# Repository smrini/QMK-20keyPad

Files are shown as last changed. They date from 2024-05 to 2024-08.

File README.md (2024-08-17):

# Custom QMk 20KeyPad 
Unleash enhanced productivity and personalize your workflow with this customizable 20-key macro keypad. This project empowers you to craft intricate macros, shortcuts, and key combinations that seamlessly integrate with your existing setup.

# Key Advantages:

* QMK Compatibility: QMK unlocks a universe of possibilities – program sophisticated macros, intricate key combinations, and layer functionalities to tailor the keypad precisely to your needs.
* 20-Key Matrix Design: Space-saving matrix layout that allows you to create a compact yet efficient keypad that perfectly complements your workspace. Whether you favour dedicated media controls, application launchers, or complex macros...
* RP2040 Microcontroller: The RP2040zero ensures smooth performance for a cheap price. 
* Multi-layer design: A functionality that gives the ability to do more than one thing to the same switch. or maybe a different layout for different uses.
* Embrace Customization: This project serves as a foundation for your creativity! Feel free to adapt the design to your preferred layout to create functionalities that perfectly align with your workflow.

# Building Your Macro Keypad:

Hardware Procurement:

* RP2040 microcontroller board (e.g., Raspberry Pi Pico)
* 20 Mechanical keyboard switches (select the switch type that best suits your typing preference – tactile, clicky, or linear)
* Keycaps (ensure compatibility with your chosen switches)
* Diodes (optional, for improved matrix scanning)
* copper wires
* 3D-printer (Or Order it online)

Required Skills:

* The knowledge of what is command line.
* An idea about QMK MSYS Commands.
* Previous use of Visual Studio (If you are planning to modify the code).
* Soldering skills

Advanced skills:
* C programming.
* .json files.
* qmk firmware.

Software Arsenal:

* [QMK Firmware](https://docs.qmk.fm/)
  
* [QMK MSYS](https://msys.qmk.fm/)

* Text editor or IDE of your choice (e.g., Visual Studio Code)

# Documentation:

Detailed instructions for hardware assembly, firmware flashing, and keymap configuration will be readily available within the project repository. Additionally, the repository may include resources or links to helpful guides that provide further assistance with the build and programming process.

You can find further information about the 3D model on my [Printables](https://www.printables.com/@GreenBit_1562343) Profile. Also [Here](https://www.printables.com/model/841830-qmk-20keymacropad), or directly [Here](https://github.com/smrini/QMK-20keyPad/tree/main/Assets/Building%20Guide).

# Contributions:

This is a collaborative effort! We welcome contributions from the keyboard enthusiast community. Submit pull requests with enhancements, bug fixes, or innovative features to help us build a robust and feature-rich macro keypad solution.

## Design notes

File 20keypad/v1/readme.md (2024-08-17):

# Handwired 20keyPad v1

20KeyPad

A 20 Key (4x5) Macropad that could be reprogrammed to suit your need, it has got 3 layers, and all the needed files are included (QMK files, 3D printables files, Buttons labels...). [More info on my github](https://github.com/smrini/QMK-20keyPad)

-   Keyboard Maintainer: [Said Mrini](https://github.com/smrini).
-   Personal Website: www.saidmrini.com

## Hardware Supported:

You can use the RP2040zero or any other microcontroller from the same series (RP2040).
You can't use a PCB, because the space is a bit tight, So you will have to hand-wire everything.

## Hardware Availability:

-   MicroController: [rp2040zero](https://es.aliexpress.com/item/1005006051130777.html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)
-   Diodes:[1N4148](https://es.aliexpress.com/item/1005006127068810.html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)
-   Keycaps: [Black and white keycaps](https://es.aliexpress.com/item/1005006213262185.html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) 
- Switches: [Red Switches](https://es.aliexpress.com/item/1005005908829758.html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)
-   3D files: [Printables](https://www.printables.com/model/841830-qmk-20keymacropad)

### Compiling example for this keyboard:

    qmk compile -kb 20keypad/v1 -km default

### Flashing example for this keyboard:

    qmk flash -kb 20keypad/v1 -km default

### Attention:

    You can compile and use the code as it is as long as you are using the same microcontroller and the same pins used in the schematic.

    just download the files, open QMK MSYS and use this command: qmk flash -kb 20keypad/v1 -km default
    You can modify the code and layers to whatever it suits you.

    if you decide to use different pins, you must change the Pinout in the keyboard.json file.
    if you decide to use a different MicroController, you must change some related information in the keyboard.json file.

See the [build environment setup](https://docs.qmk.fm/#/getting_started_build_tools) and the [make instructions](https://docs.qmk.fm/#/getting_started_make_guide) for more information. Brand new to QMK? Start with our [Complete Newbs Guide](https://docs.qmk.fm/#/newbs).

## Bootloader

Getting into bootloader:

-   **Physical reset button**: there are 2 buttons on the back of the PCB - press and hold the Boot button, don't leave it yet, press the reset button one time, after you leave it, remove your hand from the boot button.
-   **Keycode in layout**: Press and hold the 3rd key from left on the top row then press the last key on the same row. The LED will blink 3 times, then hold in red, till the flash is complete

## Useful Resources:

-   [keykodes list](https://docs.qmk.fm/#/keycodes)
-   [Matrix and hand wiring](https://docs.qmk.fm/#/hand_wire)
-   [more about info.json file](https://github.com/qmk/qmk_firmware/blob/master/docs/reference_info_json.md)
-   [More about the Keymap.c file](https://github.com/qmk/qmk_firmware/blob/master/docs/keymap.md)
-   [RGB Light](https://docs.qmk.fm/#/feature_rgblight)
-   [Command Line](https://github.com/qmk/qmk_firmware/blob/master/docs/cli_commands.md)

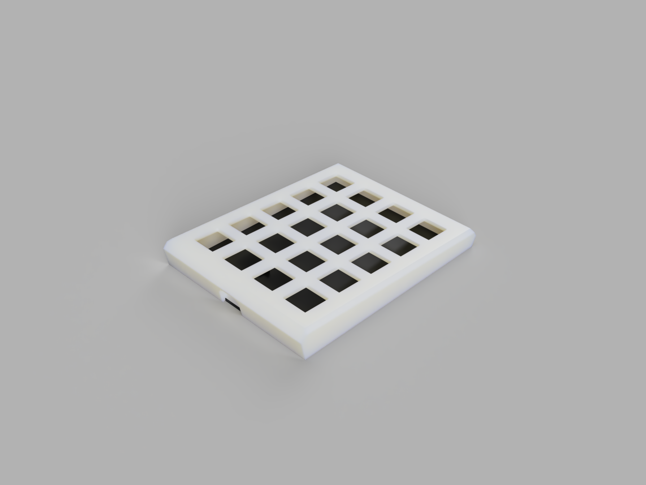
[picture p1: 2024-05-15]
Assets/20KeyPad-V1/Pictures/frame.3.png

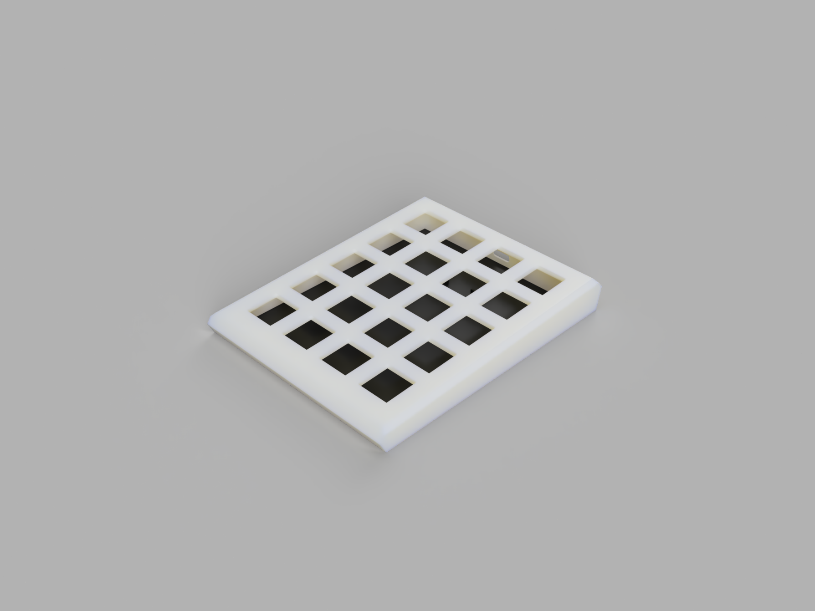
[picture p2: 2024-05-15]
Assets/20KeyPad-V1/Pictures/frame.0.png

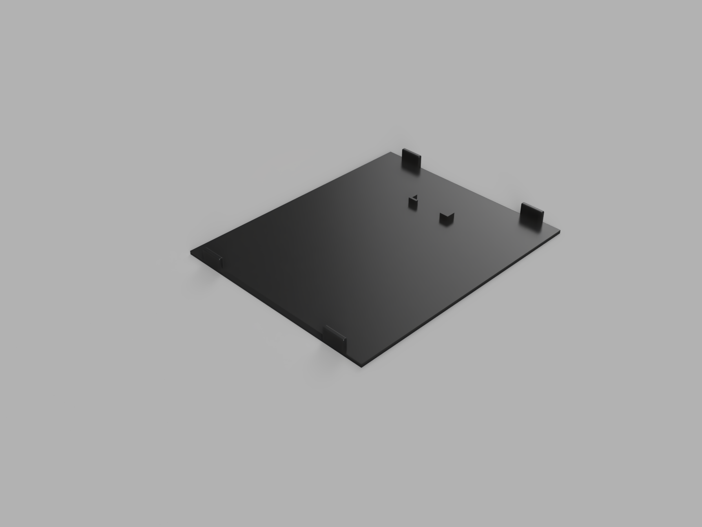
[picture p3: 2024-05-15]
Assets/20KeyPad-V1/Pictures/NumPad_2024-May-01_11-30-11PM-000_CustomizedView23081530173_png.png

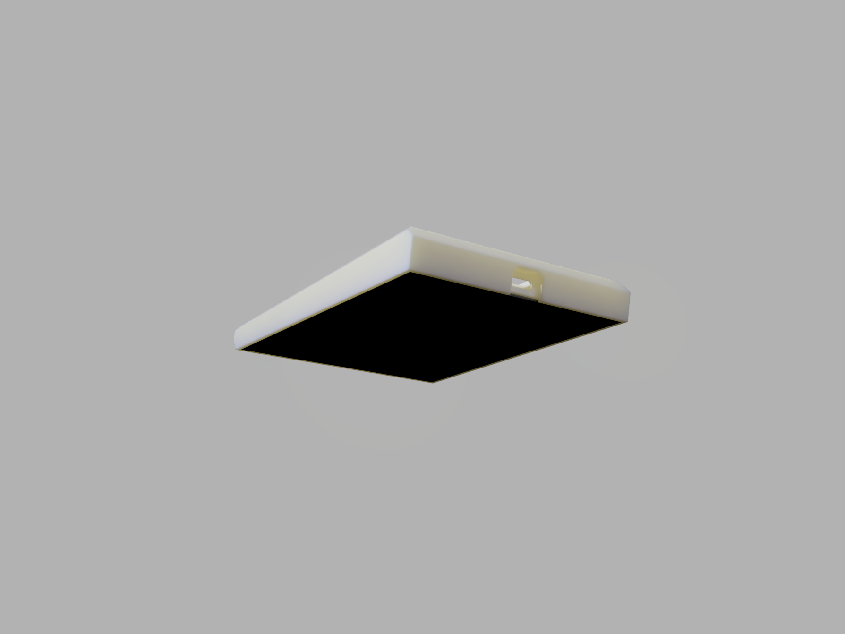
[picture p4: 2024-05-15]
Assets/20KeyPad-V1/Pictures/NumPad_2024-May-01_10-13-29PM-000_CustomizedView15163384461_png.png

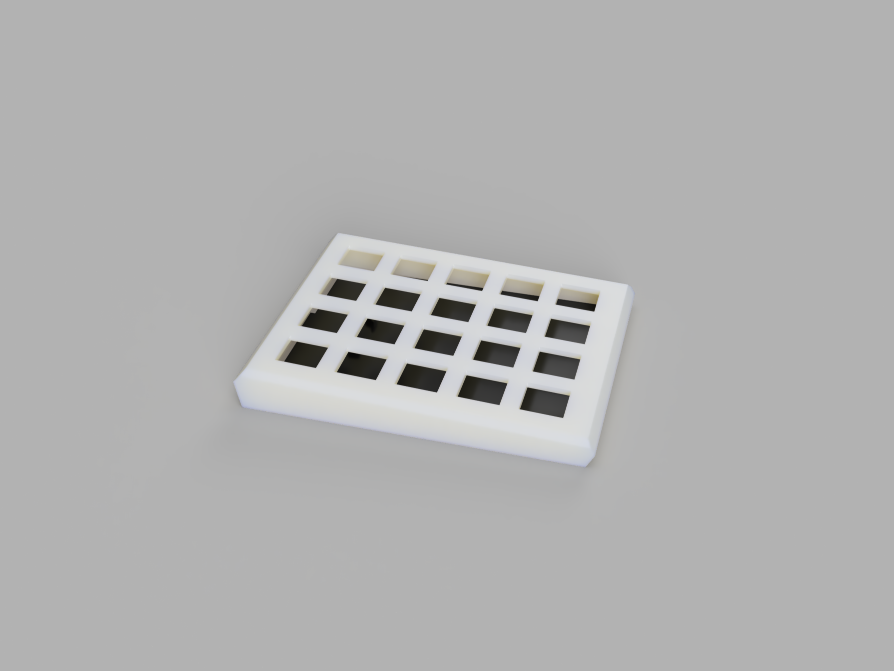
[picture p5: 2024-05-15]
Assets/20KeyPad-V1/Pictures/frame.2.png

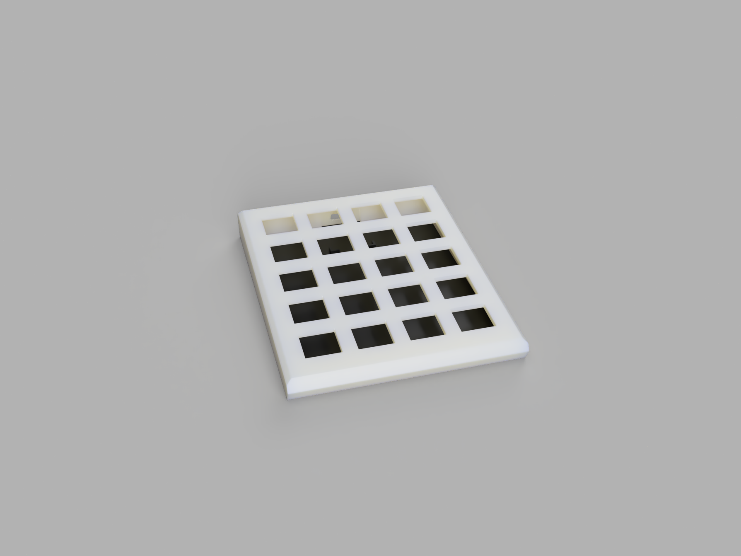
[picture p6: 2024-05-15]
Assets/20KeyPad-V1/Pictures/frame.1.png

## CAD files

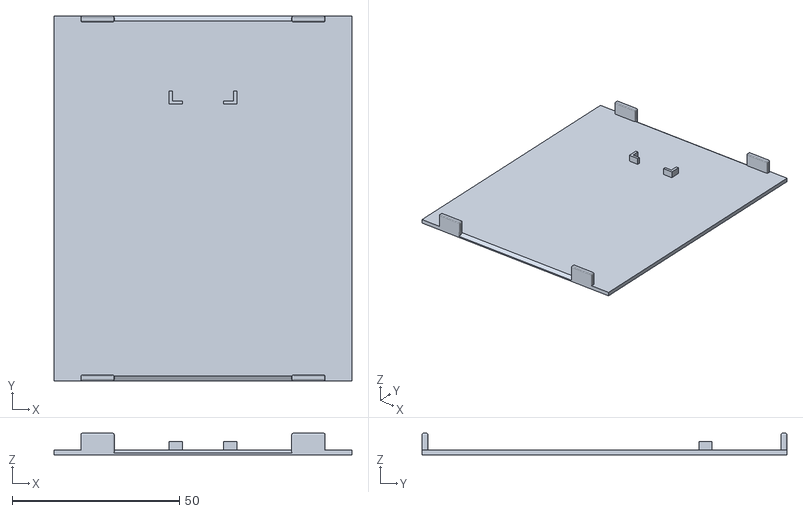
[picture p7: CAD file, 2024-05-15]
Assets/20KeyPad-V1/3D-Files/NumPad-BottomCover.stl
89.0 x 109.0 x 6.50

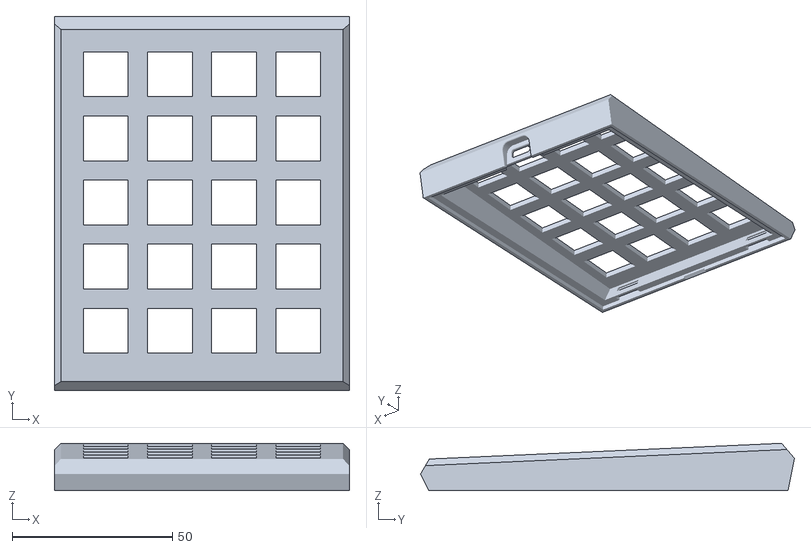
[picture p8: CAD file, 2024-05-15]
Assets/20KeyPad-V1/3D-Files/NumPad-Enclosure.stl
92.0 x 116.6 x 14.8

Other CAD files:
Assets/20KeyPad-V1/3D-Files/20KeyPad-V1.f3d

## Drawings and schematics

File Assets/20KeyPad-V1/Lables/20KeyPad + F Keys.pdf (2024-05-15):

7 | 8 | 9 | /

*

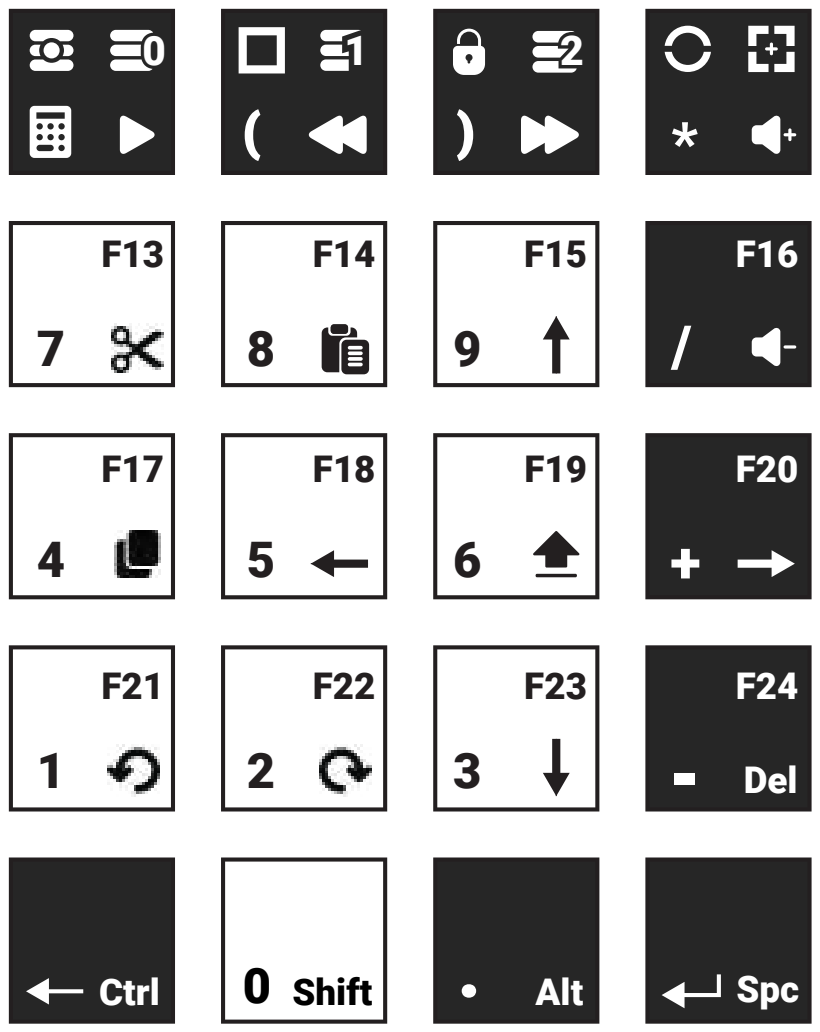
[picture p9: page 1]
Ctrl; 0 Shift; Alt; Spc; Del

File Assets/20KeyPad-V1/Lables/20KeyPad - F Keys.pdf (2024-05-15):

7 | 8 | 9 | /

*

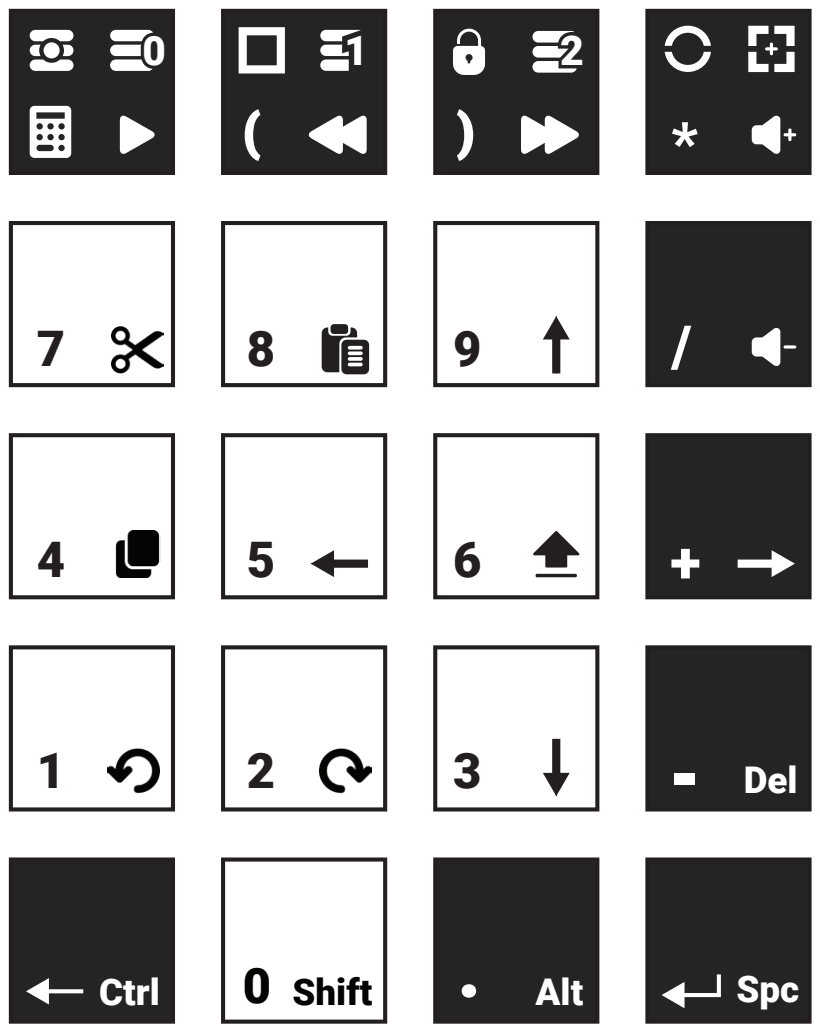
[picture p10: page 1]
Ctrl; 0 Shift; Alt; Spc; Del

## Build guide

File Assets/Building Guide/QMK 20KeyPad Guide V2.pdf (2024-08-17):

# QMQ 20KeyPad

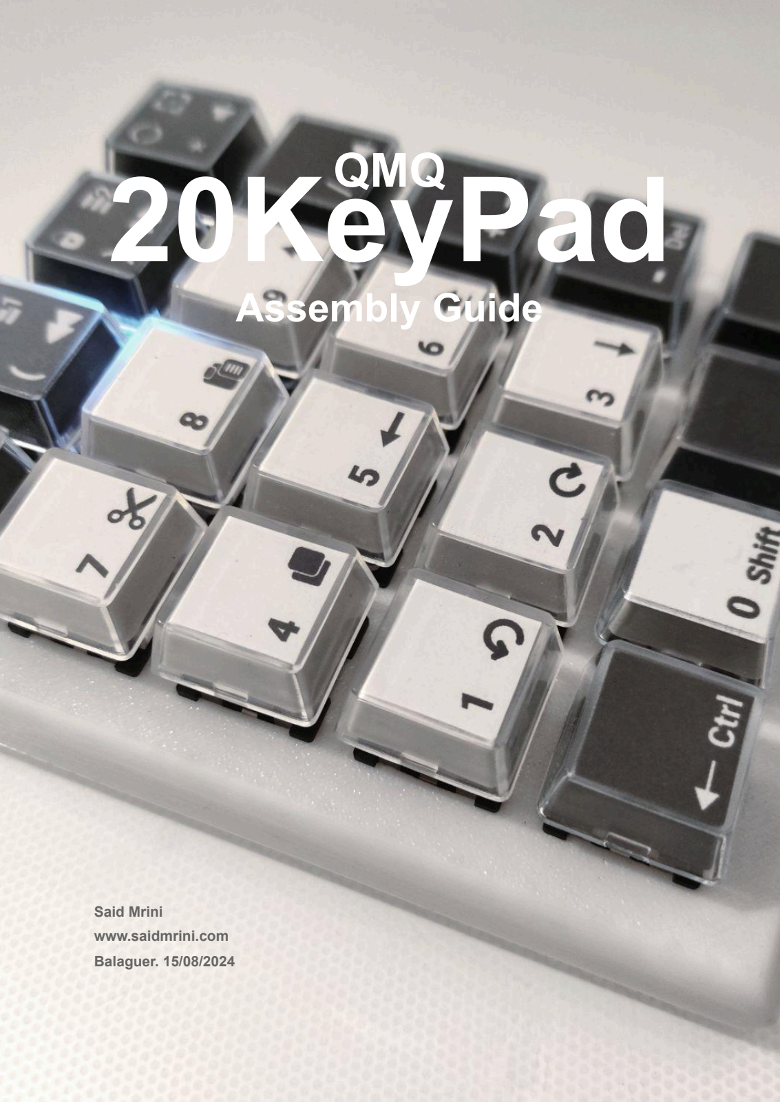
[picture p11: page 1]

# Assembly Guide

Said Mrini
www.saidmrini.com
Balaguer. 15/08/2024

# Index

QMQ | 1
20KeyPad | 1
Introducing the 20Keypad | 4
Technical information (Could be Fun) | 6
Assembly Guide (The Fun Part) | 7
Preparing the firmware | 15
Flashing the Firmware | 17
Method 1: | 17
Method 2: | 17
Bonus Tip: | 18
Useful Resources | 19
Extra Tips | 20

## Introducing the 20Keypad

The 20Keypad is a customisable macropad designed to streamline your workflow and boost efficiency. This compact, 20-key peripheral leverages the power of QMK firmware, allowing you to program each key with macros, application shortcuts, or frequently used functions.

This could come in handy if you have a laptop or a small size keyboard, the 20Keypad minimises context switching and keeps essential commands readily at your fingertips.

This guide will walk you through the entire process of building your own 20Keypad, from gathering the parts to flashing the QMK firmware and customizing your keys. By the end, you'll have a unique and powerful macropad that perfectly fits your needs.

Materials

- List all the components required for the project including:
- RP2040zero microcontroller board (Or any similar board)
- 20 Mechanical keyboard switches (select the switch type that best suits your typing preference – tactile, clicky, or linear)
- Keycaps (ensure compatibility with your chosen switches)
- Diodes
- copper wires
- 3D-printer (Or Order the enclosure from an online provider)

These are the same ones I have used:

- MicroController: rp2040zero. (https://es.aliexpress.com/item/1005006051130777.html)
- Diodes:1N4148. (https://es.aliexpress.com/item/1005006127068810.html)
- 3D files: Printables. (https://www.printables.com/model/841830-qmk-20keymacropad)
- Keycaps: Black and white keycaps. (https://es.aliexpress.com/item/1005006213262185.html?srcSns=com.microsoft.emmx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)
- Switches: Red Switches. (https://es.aliexpress.com/item/1005005908829758.html?srcSns=com.microsoft.emmx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)

Tools
- Soldering iron.
- Wire cutters and strippers
- Pliers (optional)
- Multimeter (optional, for troubleshooting)

Softwares:

- QMK MSYS (https://msys.qmk.fm/)
- IDE: VS Code, (https://code.visualstudio.com/) in case you want to customize the keymap.

Required Skills

- The knowledge of what is a command line.
- An idea about QMK MSYS Commands.
- Previous use of Visual Studio (If you are planning to modify the code).
- Soldering skills

Advanced skills

- C programming.
- .json files.
- qmk firmware.

## Technical information (Fun Stuff)

The first thing you need to learn is how keyboards work and what a matrix is. I am too lazy to explain it myself, but I am going to leave some links that can help you figure it out.
How a Keyboard Matrix Works | QMK Firmware (https://docs.qmk.fm/how_a_matrix_works)

This one would be more entertaining because it contains some colourful things called pictures.
Hand-Wiring Guide (https://docs.qmk.fm/hand_wire)
Janzon's projects (https://johannes-jansson.github.io/projects/2018/07/23/hand-wiring-lets-split.html)

These could be more fun to watch because they contain more of those colourful things but in a moving form. I asked the passenger by my side and he told me it has a name and they call it Video. Fascinating isn’t it?
(Don't ask me about the look on his face, I don't know why he is staring at me like that!)
How a Mechanical Keyboard Works (Matrix and Direct Wiring) (https://youtu.be/7LyziNdFlew)
How to Build a Handwired Keyboard by Joe Scotto (https://youtu.be/hjml-K-pV4E)

## Assembly Guide (The Fun Part)

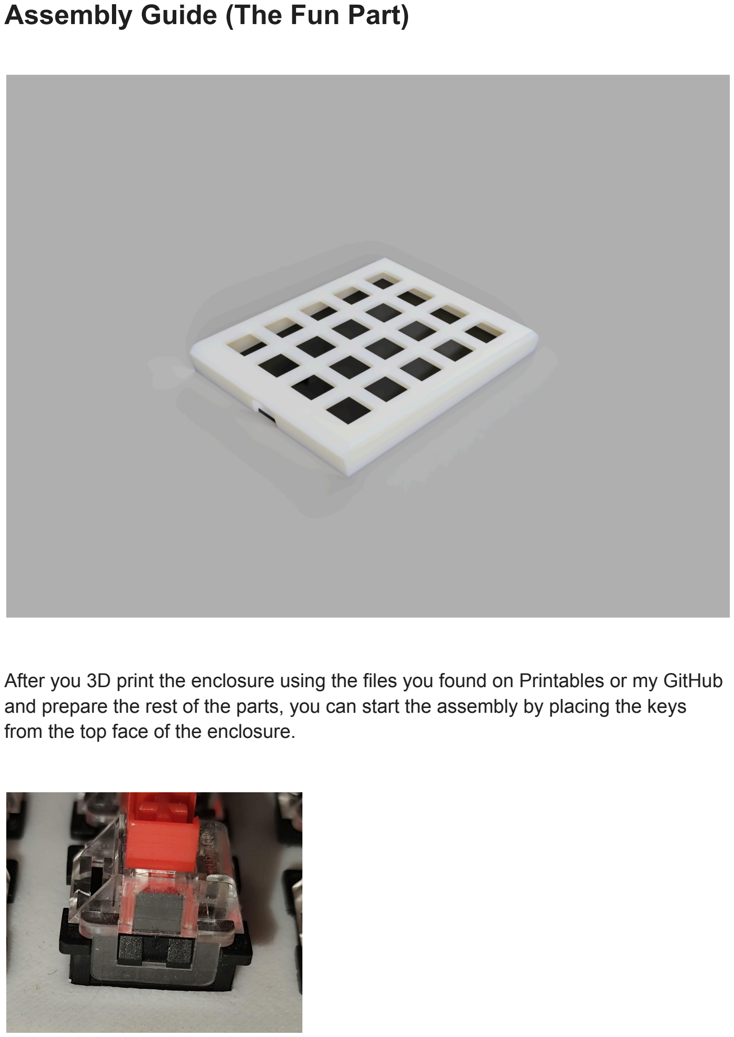
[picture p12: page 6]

After you 3D print the enclosure using the files you found on Printables or my GitHub and prepare the rest of the parts, you can start the assembly by placing the keys from the top face of the enclosure.

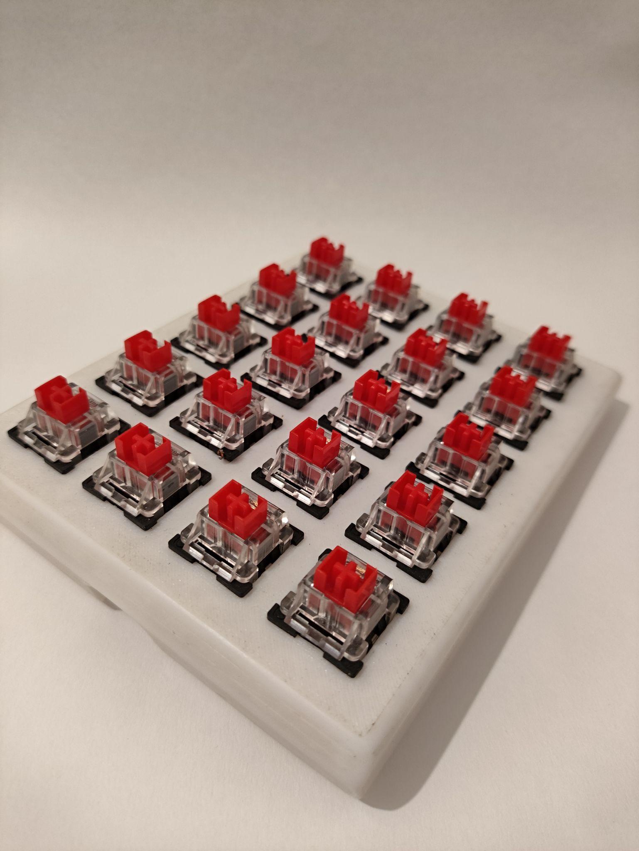
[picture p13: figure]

Follow this schematic and connect all the components as they should be.

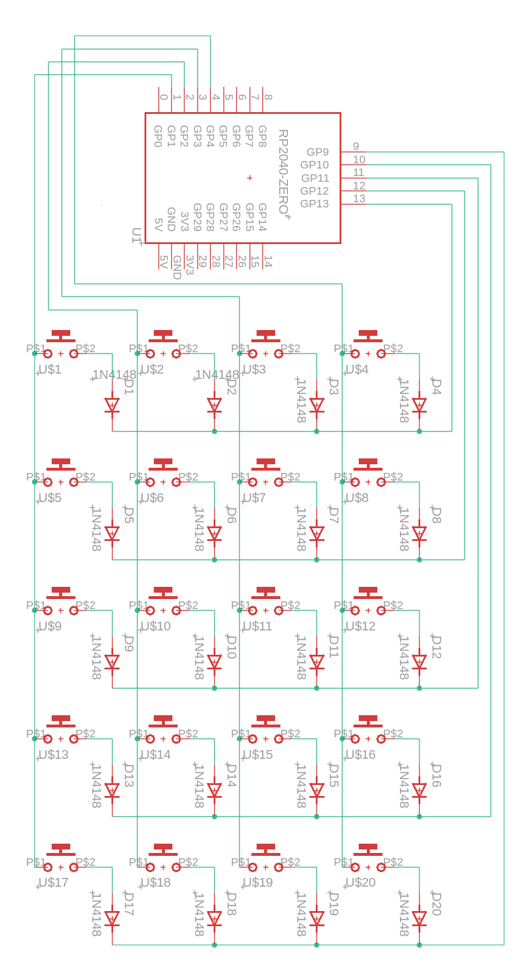
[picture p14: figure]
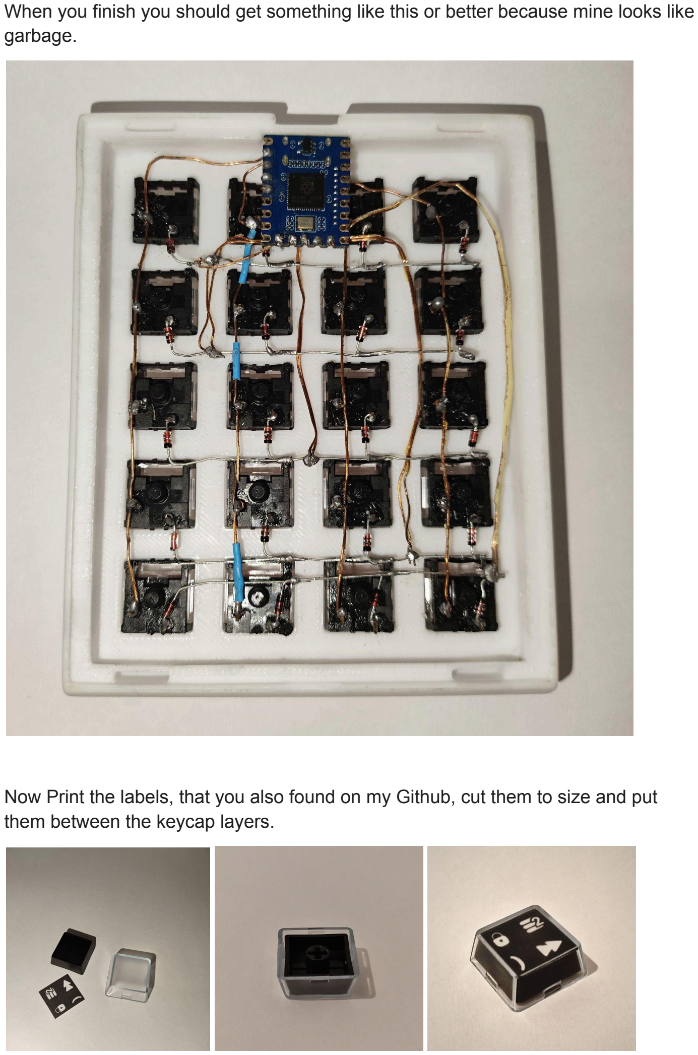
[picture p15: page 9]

When you finish you should get something like this or better because mine looks like garbage.

Now Print the labels, that you also found on my Github, cut them to size and put them between the keycap layers.

Put everything together, close it up, and you are done 👌.

If you are wondering why I didn’t use a PCB, it’s going to look like this:

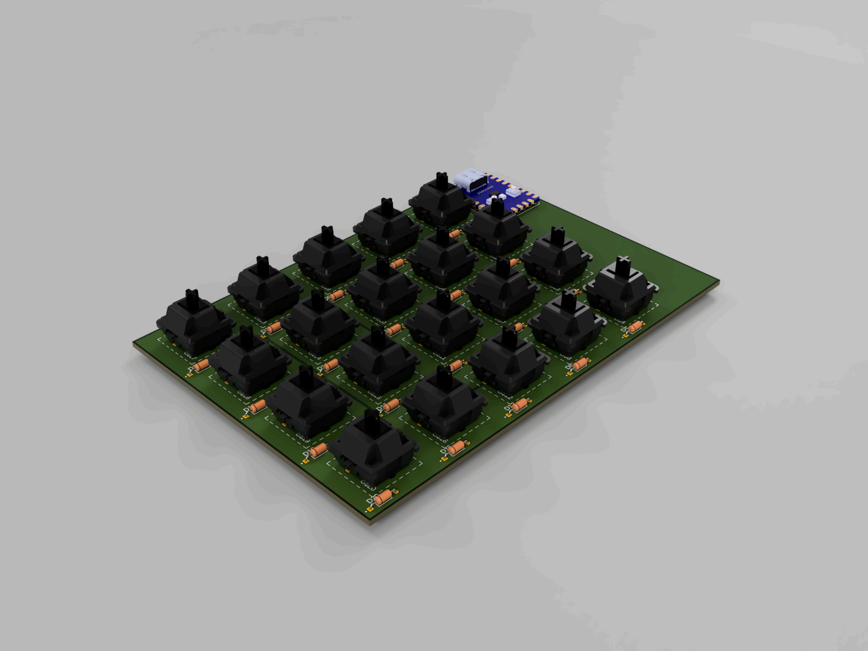
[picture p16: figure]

The microcontroller cant be placed on the underside of the PCB and it will have to be placed in a separate place which going to use more space in ower design for nothing.
Also, Handwiring components and soldering are fun, just don’t burn your selfe😊.

## Preparing the firmware

1. First, go to the QMK Msys Website, download QMK_MSYS.exe and install it

from here. (https://msys.qmk.fm/)

2. Look for it on the Windows menu and launch it
3. Then you will have to clone the qmk_firmware from my GitHub.

git clone --depth 1
https://github.com/smrini/qmk_firmware.git"C:\dev\IDEs\qmk_firmware"

You can change the Directory "C:\dev\IDEs\qmk_firmware" or leave it as

it is, You just have to make sure that it ends up with qmk_firmware, and there is no

spaces or special characters on the path.

These steps could take some time, 5-15 minutes.

4. When it finishes run this command:

qmk doctor

If it prompts you to answer Yes or No, just write y and heat enter.

5. Now go to the directory where you installed qmk-firmware, and check that all

the needed files are in this directory. if you used the same directory as me,

you should find them here.

C:\dev\IDEs\qmk_firmware\keyboards\20keypad\v1

└───v1
│ keyboard.json
│ readme.md
└───keymaps
└───default
keymap.c

6. now to test everything, run this command:

qmk compile -kb 20keypad/v2 -km default

If everything is compiled correctly you should see something like this on the

CLI

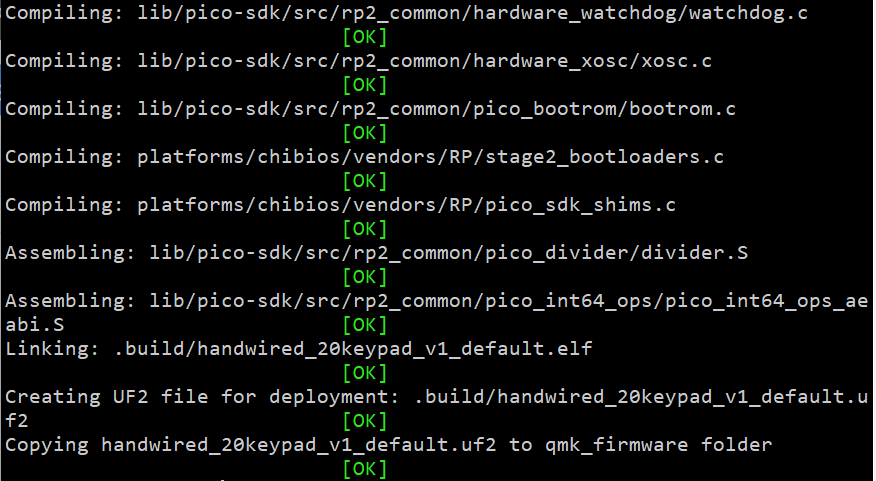
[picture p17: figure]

## Flashing the Firmware

Method 1:

Flashing the Firmware if you are using the same microcontroller and the same

pinout.

1. Put the RP2040 microcontroller board into bootloader mode
i. Physical reset button: there are 2 buttons on the back of the

PCB - press and hold the Boot button, don't leave it yet, press

the reset button one time, after you leave it, remove your hand

from the boot button.

2. Open the QMK MSYS and write this command
a. qmk flash -kb 20keypad/v1 -km default

Where 20keypad/v1 is the directory where our firmware files exist.

3. That’s it!

Method 2:

Flashing the Firmware if you are using a different microcontroller, a different pinout,

or in case you want to customize the firmware.

1. Go to this Directory.

C:\dev\IDEs\qmk_firmware\keyboards\20keypad\v1

2. Open the keyboard.json file in VS-Code and modify what you want, remember

to change this part for the microcontroller and pinout you are using.

"matrix_pins": {
"cols": ["GP4", "GP3", "GP2", "GP1"],
"rows": ["GP9", "GP10", "GP11", "GP12", "GP13"] },

"diode_direction": "COL2ROW", "processor": "RP2040",
"bootloader": "rp2040",
3. Compile the firmware using the QMK MSYS running this command
4. qmk compile -kb 20keypad/v2 -km default
5. Put the RP2040 microcontroller board into bootloader mode
a. There are 2 buttons on the back of the PCB - press and hold the Boot

button, don't leave it yet, press the reset button one time, after you

leave it, remove your hand from the boot button.

6. Open the QMK MSYS and write this command
a. qmk flash -kb 20keypad/v1 -km default
Where 20keypad/v1 is the directory where our firmware files exist.
7. That’s it!

Testing

- Once flashed, connect the macropad to your computer using a USB-C cable.
- Use a keyboard tester (https://config.qmk.fm/#/test) to verify that all the keys are working correctly.

## Bonus Tip:

After the first successful compilation, you won't need to open the macropad to press

the buttons on the microcontroller, you just have to go to layer number 2 by holding

the 3rd key from left on the first row, and then press the 4th key on the same row

## Useful Resources

First, you will have to install QMK MSYS, you can find it on this website: HERE (https://github.com/qmk/qmk_distro_msys/releases/tag/1.9.0)

to set the environment, you can follow this guide:
HERE (https://docs.qmk.fm/#/newbs_getting_started)

to build your first project you can follow this guide:
HERE (https://docs.qmk.fm/#/newbs_building_firmware)

to load the firmware to your keyboard, you can use QMK ToolBox, which you can download from this link
HERE (https://github.com/qmk/qmk_toolbox/releases)

or you can flush it using the Command line:
HERE (https://docs.qmk.fm/#/newbs_flashing)

to configure VS Code for QMK, you can check this link: HERE (https://docs.qmk.fm/#/other_vscode)

key-codes list:
HERE (https://docs.qmk.fm/#/keycodes)

A blog that may contain some useful things:
HERE (https://thomasbaart.nl/category/mechanical-keyboards/firmware/qmk/qmk-basics/)
Space Cadet:
"tap Right Shift on its own and you get the closing one. When held, the Shift keys function as normal."
HERE (https://docs.qmk.fm/#/feature_space_cadet)

Tap Dance:
"Doing different things depends on how many times you taped the key, once, twice, three times, or more..."
HERE (https://docs.qmk.fm/#/feature_tap_dance)

more about .jason file:
HERE (https://github.com/qmk/qmk_firmware/blob/master/docs/reference_info_json.md)

Full list of keycodes used in QMK for Keymaps: HERE (https://github.com/qmk/qmk_firmware/blob/master/docs/keycodes.md)

More about the Keymap.c file:
HERE (https://github.com/qmk/qmk_firmware/blob/master/docs/keymap.md)

RGB Light:
HERE (https://docs.qmk.fm/#/feature_rgblight)

Instructions for the make command HERE (https://docs.qmk.fm/#/getting_started_make_guide)

## Extra Tips

- You have done it, you just successfully built your own custom macropad!
- If you want to get further into it and customize the Keypad more, you can read

the qmk documentation. (https://docs.qmk.fm/#/)

- Using the same Microcontroller, diode direction, and pinout would make life a

lot easier, the other parts won't make any real difference.

- you still can use a different microcontroller, or customize the files, but I don’t

recommend that unless you are a pro.

- Try using different switches or keycaps to suit your preferences.
- The links I have provided for buying the parts, aren't an affiliate link and are

just an example, so you may be able to find cheaper ones.

- I am really glad you have made it here, and I just want to thank you and say:

Few are the people that may come to this point, and make their custom

keyboard, but just the idea of making something from the ground means that

you are trying to make a difference.

I am waiting for it 🙃.

Just another thing before you go. you may want to check my profiles from

time to time, you could find a project that you may enjoy.

My Personal Website, (http://saidmrini.com) Behance, (https://www.behance.net/said-mrini) Printables… (https://www.printables.com/@GreenBit_1562343)

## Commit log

2024-05-15 Extra Assets
    [20KeyPad-V1.f3d, NumPad-BottomCover.stl, NumPad-Enclosure.stl]
2024-08-15 Update README.md
    Adding the Printables link
